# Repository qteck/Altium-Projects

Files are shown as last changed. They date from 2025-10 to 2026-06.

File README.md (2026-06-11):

# Optical Receiver Design 
The optical receiver is designed with two signal paths: one for oscilloscope monitoring and debugging, and one for audio output. The design balances bandwidth, gain, loading, noise filtering, DC offset removal, and testability. Gain is distributed across multiple stages to maintain bandwidth and reduce distortion while buffering and appropriate stage impedance ratios are used to minimize loading effects.

## Layout Characteristics
The receiver is divided into two signal paths:
- Path 1: Scope/debugging output
- Path 2: Audio output

## Design Variables Considered
The design takes into account the following trade-offs and constraints:
- Bandwidth versus signal magnitude
- Loading effect versus signal magnitude
- Signal damping versus gain
- Filtering of coupled noise using passive filters and the properties of IC packages
- Bidirectional power supply requirements
- Signal level shifting
- DfX considerations, especially design for testing

## Mitigation Techniques
The following techniques are used to improve signal quality, stability, and testability:
- Buffering to reduce loading effects 
- Consecutive stage loading with an approximate factor of 10 between stages 
- Minimising gain per stage to maximise bandwidth 
- Splitting gain across multiple stages to retain bandwidth while increasing total gain 
- Selecting appropriate gain values to minimise signal distortion 
- Using passive filters to reduce coupled noise at reasonable cost 
- Removing DC offset by introducing a high-pass filter 
- Adding test pins and debugging connections with reasonably sized components for easier testing and troubleshooting
  
## Signal Paths 
Path 1: 
Purpose: Receive optical signal and amplify the current from the detector into processable voltage levels using the sullen keys with a scope connection for debugging.

Stages: TIA → DC blocker / HPF → Sallen-Key Filter 1 → Sallen-Key Filter 2 → Scope Output

Path 2: 
Purpose: Provide audible output with industry grade audio op amp and passive low pass filter in the path.

Stages: TIA → DC blocker / HPF → Sallen-Key Filter 1 → Sallen-Key Filter 2 → LPF2 → LPF3 → Pre-Amplifier → Audio Amplifier

## PCB Front Side
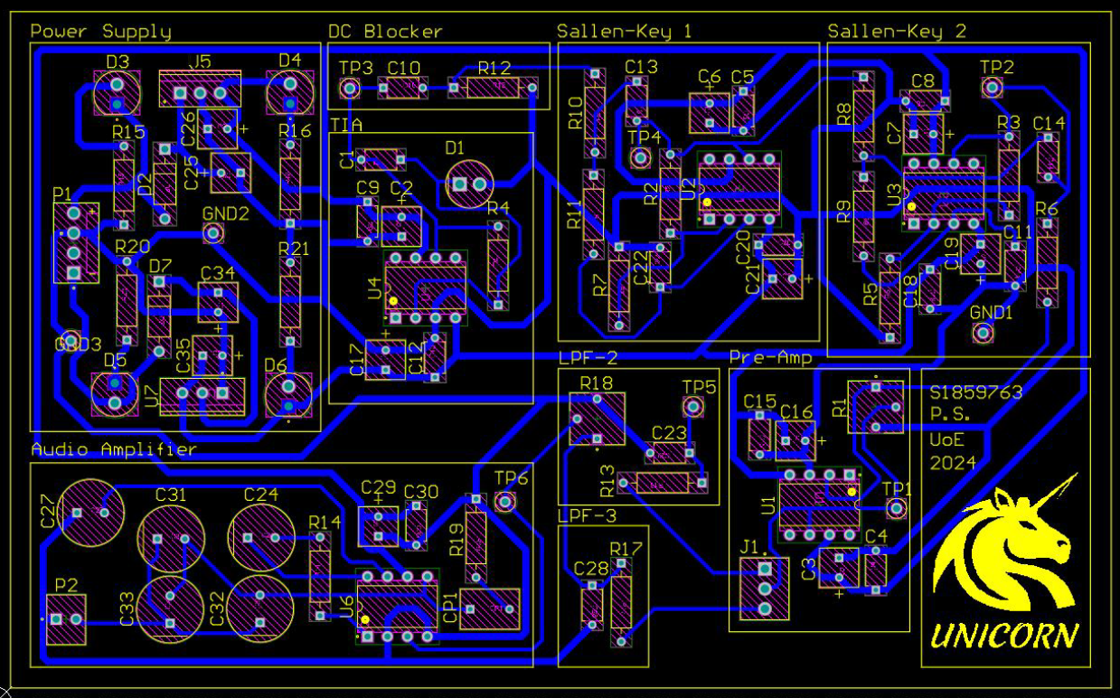
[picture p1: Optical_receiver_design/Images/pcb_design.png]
Whole System


## System Capture
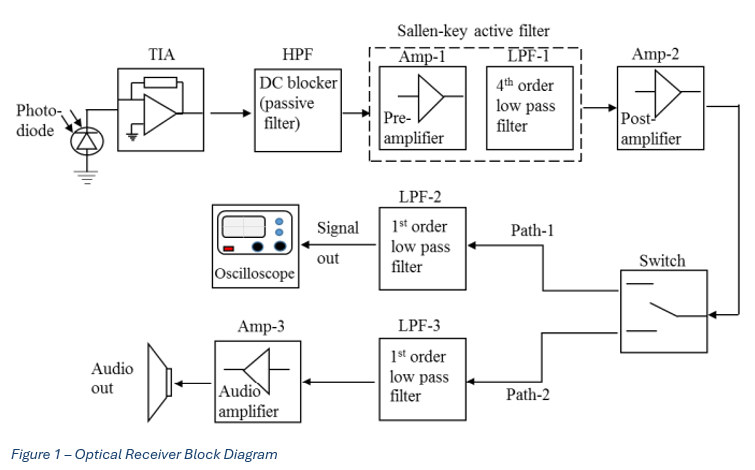
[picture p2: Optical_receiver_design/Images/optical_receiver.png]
System Capture


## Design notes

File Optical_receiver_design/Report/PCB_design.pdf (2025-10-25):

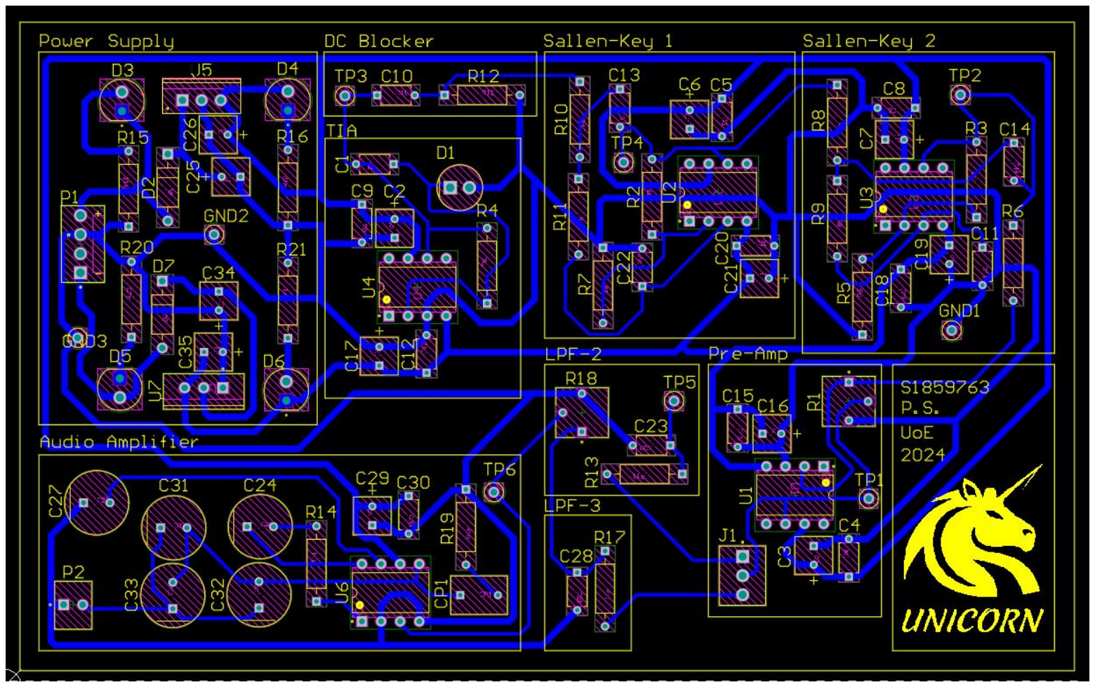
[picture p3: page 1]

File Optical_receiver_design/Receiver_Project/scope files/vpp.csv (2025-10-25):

x-axis | 1
second | Volt
-1.900000E-06 | -42.592964601E-03
-1.895000E-06 | -40.180904325E-03
-1.890000E-06 | -39.778894279E-03
-1.885000E-06 | -40.180904325E-03
-1.880000E-06 | -42.994974647E-03
-1.875000E-06 | -39.778894279E-03
-1.870000E-06 | -44.201004785E-03
-1.865000E-06 | -40.984924417E-03
-1.860000E-06 | -41.386934463E-03
-1.855000E-06 | -40.984924417E-03
-1.850000E-06 | -42.592964601E-03
-1.845000E-06 | -40.180904325E-03
-1.840000E-06 | -38.974874187E-03
-1.835000E-06 | -41.386934463E-03
-1.830000E-06 | -43.798994739E-03
-1.825000E-06 | -40.582914371E-03
-1.820000E-06 | -41.788944509E-03
-1.815000E-06 | -36.160803866E-03
-1.810000E-06 | -40.582914371E-03
-1.805000E-06 | -38.572864141E-03
-1.800000E-06 | -40.582914371E-03
-1.795000E-06 | -38.974874187E-03
-1.790000E-06 | -37.768844049E-03
-1.785000E-06 | -38.170854095E-03
-1.780000E-06 | -38.170854095E-03
-1.775000E-06 | -39.376884233E-03
-1.770000E-06 | -40.984924417E-03
-1.765000E-06 | -39.778894279E-03
-1.760000E-06 | -40.582914371E-03
-1.755000E-06 | -35.356783774E-03
-1.750000E-06 | -42.190954555E-03
-1.745000E-06 | -36.964823958E-03
-1.740000E-06 | -40.180904325E-03
-1.735000E-06 | -36.562813912E-03
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

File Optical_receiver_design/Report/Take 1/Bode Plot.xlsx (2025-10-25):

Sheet: List1
FrA1:E16eq, f(Khz) | Vin(mV) | Vout (V) | Vout/Vin | G=20log(Vout/Vin) (Db) | Vout (V) | Vout/Vin |  | G=20log(Vout/Vin) (Db) |  | Freq, f(khz) | Vin(mV) | Vout (V) | Vout/Vin | G=20log(Vout/Vin) (Db)
200 | 0.125 | 0.092 | 0.736 | -2.662 | 0.80 | #REF! |  | #REF! |  | 10 | 0.12 | 1.65 | 13.20 | 22.41
600 | 0.125 | 0.086 | 0.688 | -3.248 | 1.00 | #REF! |  | #REF! |  | 20 | 0.12 | 1.44 | 11.52 | 21.23
1000 | 0.125 | 0.074 | 0.592 | -4.554 | 1.30 | #REF! |  | #REF! |  | 30 | 0.12 | 1.22 | 9.76 | 19.79
1400 | 0.125 | 0.073 | 0.584 | -4.672 | 1.40 | #REF! |  | #REF! |  | 40 | 0.12 | 1.00 | 8.00 | 18.06
1800 | 0.125 | 0.070 | 0.560 | -5.036 | 1.50 | #REF! |  | #REF! |  | 50 | 0.12 | 0.86 | 6.88 | 16.75
2200 | 0.125 | 0.068 | 0.544 | -5.288 | 1.50 | #REF! |  | #REF! |  | 60 | 0.12 | 0.75 | 6.00 | 15.56
2600 | 0.125 | 0.066 | 0.528 | -5.547 | 1.50 | #REF! |  | #REF! |  | 70 | 0.12 | 0.68 | 5.44 | 14.71
3000 | 0.125 | 0.060 | 0.480 | -6.375 | 1.50 | #REF! |  | #REF! |  | 80 | 0.12 | 0.61 | 4.88 | 13.77
3400 | 0.125 | 0.055 | 0.440 | -7.131 | 1.60 | #REF! |  | #REF! |  | 90 | 0.12 | 0.52 | 4.16 | 12.38
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

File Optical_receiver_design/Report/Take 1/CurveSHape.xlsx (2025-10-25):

x-axis | 1
second | Volt
-2.94e-06
-2.935e-06 | -0.001459798776
-2.93e-06 | -0.001459798776
-2.925e-06 | -0.002263818868
-2.92e-06 | -0.003067838959
-2.915e-06 | -0.001459798776
-2.91e-06 | -0.005479899235
-2.905e-06 | -0.005479899235
-2.9e-06 | -0.004675879143
-2.895e-06 | -0.005479899235
-2.89e-06 | -0.002263818868
-2.885e-06 | -0.006283919327
-2.88e-06 | -0.007891959511
-2.875e-06 | -0.01110803988
-2.87e-06 | -0.004675879143
-2.865e-06 | -0.008695979603
-2.86e-06 | -0.006283919327
-2.855e-06 | -0.006283919327
-2.85e-06 | -0.007087939419
-2.845e-06 | -0.007891959511
-2.84e-06 | -0.006283919327
-2.835e-06 | -0.006283919327
-2.83e-06 | -0.007087939419
-2.825e-06 | -0.009499999695
-2.82e-06 | -0.009499999695
-2.815e-06 | -0.01191205997
-2.81e-06 | -0.007087939419
-2.805e-06 | -0.01271608006
-2.8e-06 | -0.01271608006
-2.795e-06 | -0.01271608006
-2.79e-06 | -0.01271608006
-2.785e-06 | -0.01754020061
-2.78e-06 | -0.007891959511
-2.775e-06 | -0.01754020061
-2.77e-06 | -0.01754020061
-2.765e-06 | -0.01512814034
-2.76e-06 | -0.01432412025
-2.755e-06 | -0.01754020061
-2.75e-06 | -0.01593216043
-2.745e-06 | -0.01432412025
-2.74e-06 | -0.01432412025
-2.735e-06 | -0.01834422071
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

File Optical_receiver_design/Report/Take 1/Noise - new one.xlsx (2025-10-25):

x-axis
second | Volt | Noise recorderd when V = 0.086
-2.94e-06
-2.94e-06 | 4.17E-03
-2.93e-06 | 4.97E-03
-2.93e-06 | 6.58E-03
-2.92e-06 | 2.56E-03
-2.92e-06 | 6.58E-03
-2.91e-06 | 7.38E-03
-2.91e-06 | 6.58E-03
-2.9e-06 | 3.36E-03
-2.9e-06 | 7.38E-03
-2.89e-06 | 7.38E-03
-2.89e-06 | 7.38E-03
-2.88e-06 | 5.78E-03
-2.88e-06 | 6.58E-03
-2.87e-06 | 6.58E-03
-2.87e-06 | 4.97E-03
-2.86e-06 | 3.36E-03
-2.86e-06 | 4.97E-03
-2.85e-06 | 4.17E-03
-2.85e-06 | 3.36E-03
-2.84e-06 | 4.97E-03
-2.84e-06 | 5.78E-03
-2.83e-06 | 7.38E-03
-2.83e-06 | 3.36E-03
-2.82e-06 | 4.97E-03
-2.82e-06 | 4.97E-03
-2.81e-06 | 7.38E-03
-2.81e-06 | 5.78E-03
-2.8e-06 | 4.17E-03
-2.8e-06 | 6.58E-03
-2.79e-06 | 7.38E-03
-2.79e-06 | 4.97E-03
-2.78e-06 | 1.48E-04
-2.78e-06 | 9.52E-04
-2.77e-06 | 3.36E-03
-2.77e-06 | 1.76E-03
-2.76e-06 | 4.17E-03
-2.76e-06 | 5.78E-03
-2.75e-06 | 4.97E-03
-2.75e-06 | 8.19E-03
-2.74e-06 | 6.58E-03
-2.74e-06 | 8.99E-03
-2.73e-06 | 3.36E-03
-2.73e-06 | 5.78E-03
-2.72e-06 | 4.97E-03
-2.72e-06 | 6.58E-03
-2.71e-06 | 3.36E-03
-2.71e-06 | 4.97E-03
-2.7e-06 | 4.97E-03
-2.7e-06 | 7.38E-03
-2.69e-06 | 4.97E-03
-2.69e-06 | 3.36E-03
-2.68e-06 | 5.78E-03
-2.68e-06 | 4.17E-03
-2.67e-06 | 3.36E-03
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

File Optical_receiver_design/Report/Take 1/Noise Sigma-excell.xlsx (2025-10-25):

x-axis |  | trasmitter off - noise signal
second | Volt
-2.93e-06
-2.92e-06
-2.92e-06 | -0.0568
-2.91e-06 | -0.0468
-2.91e-06 | -0.0367 |  |  |  | noise floor image
-2.9e-06 | -0.0447
-2.9e-06 | -0.0407
-2.89e-06 | -0.0528
-2.89e-06 | -0.0407
-2.88e-06 | -0.0387
-2.88e-06 | -0.0447
-2.87e-06 | -0.0387
-2.87e-06 | -0.0367
-2.86e-06 | -0.0488
-2.86e-06 | -0.0367
-2.85e-06 | -0.0367
-2.85e-06 | -0.0387
-2.84e-06 | -0.0387
-2.84e-06 | -0.0387
-2.83e-06 | -0.0387
-2.83e-06 | -0.0307
-2.82e-06 | -0.0468
-2.82e-06 | -0.0468 |  | -0.05069555208 | -0.0507
-2.81e-06 | -0.0468
-2.81e-06 | -0.0548
-2.8e-06 | -0.0407
-2.8e-06 | -0.0528
-2.79e-06 | -0.0528
-2.79e-06 | -0.0447
-2.78e-06 | -0.0548
-2.78e-06 | -0.0528
-2.77e-06 | -0.0528
-2.77e-06 | -0.0628
-2.76e-06 | -0.0468
-2.76e-06 | -0.0568
-2.75e-06 | -0.0468
-2.75e-06 | -0.0689
-2.74e-06 | -0.0628
-2.74e-06 | -0.0488
-2.73e-06 | -0.0528
-2.73e-06 | -0.0628
-2.72e-06 | -0.0628
-2.72e-06 | -0.0468
-2.71e-06 | -0.0548
-2.71e-06 | -0.0548
-2.7e-06 | -0.0548
-2.7e-06 | -0.0548
-2.69e-06 | -0.0689
-2.69e-06 | -0.0548
-2.68e-06 | -0.0468
-2.68e-06 | -0.0648
-2.67e-06 | -0.0508
-2.67e-06 | -0.0488
-2.66e-06 | -0.0608
-2.66e-06 | -0.0468
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

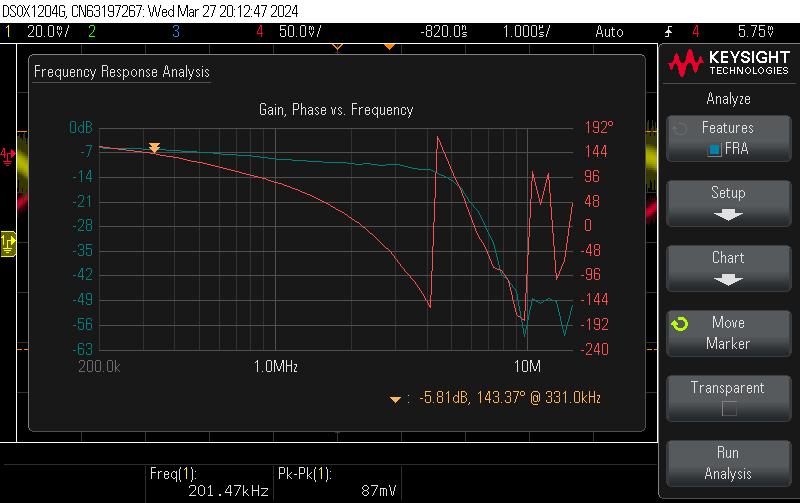
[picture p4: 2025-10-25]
Optical_receiver_design/Report/Take 3/scope_26.png

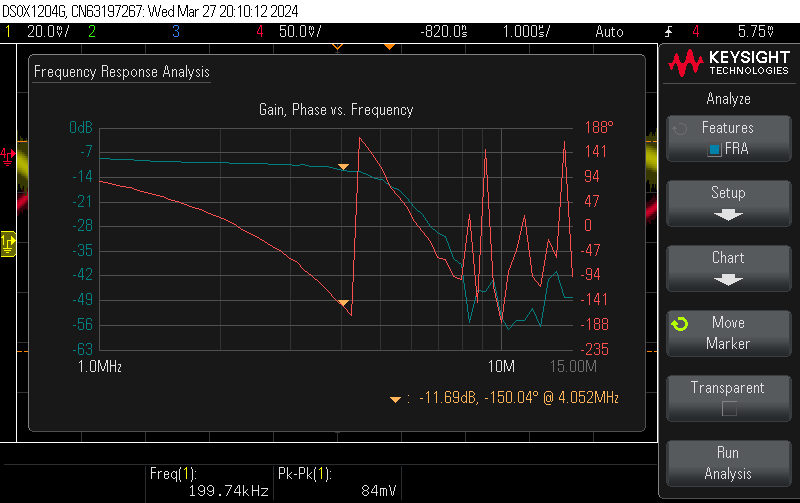
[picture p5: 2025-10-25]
Optical_receiver_design/Report/Take 3/scope_25.png

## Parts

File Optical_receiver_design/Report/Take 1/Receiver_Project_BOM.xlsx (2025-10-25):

Comment | Description | Designator | Supplier | Note | Mouser No. | Quantity | Price per 10 units | Final price
8p | Ceramic Disc Capacitors 8pF 5% | C1 | mouser.co.uk |  | 75-561R10TCCV80BA | 1 | £6.39 | £6.39
2.2u | CAP TANT 10UF 10% 16V RADIAL | C2, C3, C6, C7, C16, C17, C19, C21, C29 | 'mouser.co.uk |  | T350C225K035AT7301 | 9 | £22.50 | £202.50
0.1n | Capacitors MLCC - Leaded 100pF 50volts 5% | C4, C5, C8, C9, C12, C15, C18, C20, C30 | mouser.co.uk |  | 594-K101J15C0GF5TL2 | 9 | £0.89 | £8.01
22n | Ceramic Disc Capacitors 100V 22nF -20% | C10 | mouser.co.uk |  | 594-D223Z39Y5VH63L2R | 1 | £1.92 | £1.92
100p | Capacitors MLCC - Leaded 100pF 50V 5% | C11, C14 | mouser.co.uk |  | 594-K101J15C0GF5TH5 | 2 | £0.89 | £1.78
56p | Capacitors MLCC - Leaded 56pF 50V 5% | C13, C22 | mouser.co.uk |  | 594-K560J15C0GF5TL2 | 2 | £0.87 | £1.74
68p | Ceramic Disc Capacitors 68pF 5% 3Kvolts | C23 | mouser.co.uk |  | 75-564R3DF0Q68 | 1 | £0.82 | £0.82
10u | Electrolytic Capacitors - Radial Leaded 16VDC 10uF | C24, C27 | mouser.co.uk | for 50G | 667-ECE-A1CKS100B | 0 | £0.09 | £0.00
0.33u | Tantalum Capacitors - Solid Leaded 35volt 0.33uF 10% | C25, C34 | mouser.co.uk |  | 80-T355A334K035AT | 2 | £2.29 | £4.58
0.1u | Tantalum Capacitors- 50V 0.1uF 20% ESR = 26 Ohm | C26, C35 | mouser.co.uk |  | 581-TAP104M050CCS | 2 | £0.32 | £0.64
1n | Capacitors MLCC - Leaded 1000pF 50volts 5% | C28 | mouser.co.uk |  | 594-K102J15C0GF5TH5 | 1 | £0.18 | £0.18
47uF | Electrolytic Capacitor - Radial Leaded 100VDC 47uF 590mA | C31 | mouser.co.uk |  | 667-EEU-FS2A470LB | 1 | £0.31 | £0.31
100uF | Electrolytic Capacitors - Radial Leaded 25VDC 100uF | C32, C33 | mouser.co.uk |  | 667-ECE-A1EKS101I | 2 | £0.22 | £0.44
47n | Film Capacitors 0.047uF 100V 5% | CP1 | mouser.co.uk |  | 75-MKT1817347014 | 1 | £0.43 | £0.43
78-TEFD4300F | Photodiodes T-1 770 to 1070nm +/-20 deg | D1 | mouser.co.uk |  | 78-TEFD4300F | 1 | £3.33 | £3.33
1N4007 | Rectifiers Diode, DO-41, 1000V, 1A | D2, D2 | mouser.co.uk |  | 637-1N4007 | 2 | £0.05 | £0.11
RED | Standard LEDs - Through Hole, T-1 3/4 (5 mm) | D3, D5 | mouser.co.uk |  | 645-521-9651F | 2 | £8.86 | £17.72
GREEN | Standard LEDs - Through Hole, T-1 3/4 (5 mm) | D4, D6 | mouser.co.uk |  | 645-521-9651F | 2 | £8.86 | £17.72
Test pins | Test Plugs & Test Jacks BLACK TEST POINT | GND1, GND2, GND3 | mouser.co.uk |  | 534-5011 | 3 | £1.76 | £5.28
Slide Switch | Slide Switches 8.8 x 3.9 x 3.5 mm, 2 mm | J1 | mouser.co.uk |  | 179-SLW-883935-2A-D | 1 | £3.50 | £3.50
Power connection | Male Header, Pitch 2.54 mm, 1 x 4 Pos, Height 10.03 mm, Tail Length 3.56 mm | P1 | mouser.co.uk |  | 571-2369991-4 | 1 | £18.70 | £18.70
Board output | Female Header, Pitch 2.54 mm, 1 x 2 Pos, Height 10.67 mm, Tail Length 3.56 mm | P2 | mouser.co.uk |  | 649-71363-302LF | 1 | £2.30 | £2.30
Trimmer pot 100k | Trimmer 104 - 'Through Hole 1/4"SQ 100KOHMS 10% | R1 | mouser.co.uk |  | 652-3362U-1-104ALF | 1 | £11.60 | £11.60
1.8k | Resistor 2W, 500V, 5% | R2, R3 | uk.farnell.com |  | 3229913 | 2 | £2.90 | £5.80
3k3 | 5W, 500V, 5% | R4 | uk.farnell.com |  | 2324626 | 1 | £3.80 | £3.80
2.2k | 5W, 500V, 5% | R5, R7 | uk.farnell.com |  | 1306252 | 2 | £4.70 | £9.40
10k | 5W, 500V, 5% | R6 | uk.farnell.com |  | 3229934 | 1 | £3.90 | £3.90
270 | '5W, 500V, 5% | R8, R9 | uk.farnell.com |  | 3229892 | 2 | £3.90 | £7.80
470 | '5W, 150V, 5% | R10, R11 | uk.farnell.com |  | 2340995 | 2 | £4.70 | £9.40
4k7 | '5W, 500V, 5% | R12 | uk.farnell.com |  | 3229925 | 1 | £3.90 | £3.90
330 | '5W, 500V, 5% | R13 | uk.farnell.com |  | 3229894 | 1 | £3.90 | £3.90
1k2 | '5W, 500V, 5% | R14 | uk.farnell.com | for 50G | 3605426 | 0 | £4.90 | £0.00
2k2 | '5W, 500V, 5% | R15, R20 | uk.farnell.com |  | 3229915 | 2 | £3.80 | £7.60
33K | '5W, 500V, 5% | R16, R21 | uk.farnell.com |  | 3229947 | 2 | £4.00 | £8.00
1k5 | '5W, 500V, 5% | R17 | uk.farnell.com |  | 3229911 | 1 | £3.10 | £3.10
Trimmer pot 10k | Trimmer Resistors - Through Hole 1/4"SQ 10KOHMS 10% | R18 | uk.farnell.com |  | 652-3362H-1-103LF | 1 | £10.30 | £10.30
10 | RES 1K OHM 0.6W 1% AXIAL | R19 | uk.farnell.com |  | 3229854 | 1 | £4.00 | £4.00
Test pins | Test Plugs & Test Jacks BLACK TEST POINT | TP1, TP2, TP3, TP4, TP5, TP6 | mouser.co.uk |  | 534-5011 | 6 | £1.76 | £10.56
LM6171 | High Speed Low Power Low Distortion Voltage Feedback Amplifier, 8-pin MDIP | U1, U2, U3 | mouser.co.uk |  | 926-LM6171BIN/NOPB | 3 | £38.60 | £115.80
LM318N | Operational Amplifier, 8-pin MDIP | U4 | mouser.co.uk |  | 595-LM318P | 1 | £11.50 | £11.50
LM78L12ACZ | Positive Voltage Regulator, 5V, 3-Pin TO-220 | U5 | mouser.co.uk |  | 926-LM78L12ACZ/NOPB | 1 | £4.88 | £4.88
LM386N-1 | Low Voltage Audio Power Amplifier, 0 to 70 degC, 8-pin DIP (P8) | U6 | mouser.co.uk |  | 926-LM386N-1/NOPB | 1 | £7.59 | £7.59
LM79L12 | 3-Terminal Negative Regulator, 3-pin TO-220, Pb-Free | U7 | mouser.co.uk |  | 863-MC79L12ACPRPG | 1 | £2.70 | £2.70
 | PCB | PCB | jlcpcb.com |  |  | 1 | £2.00 | £2.00
 | 8 DIP amplifier sockets, 2.54 mm, 7.62 mm | Socket U1, U2, U3, U4 | uk.farnell.com |  | 2445620 | 0 | £1.69 | £0.00
 | Shipment | Transport | FedEX |  |  | 1 | £20.00 | £20.00
 |  |  |  |  |  |  | Total per 10 units | £543.93
 |  |  |  |  |  |  | Total per 1 unit | £54.39

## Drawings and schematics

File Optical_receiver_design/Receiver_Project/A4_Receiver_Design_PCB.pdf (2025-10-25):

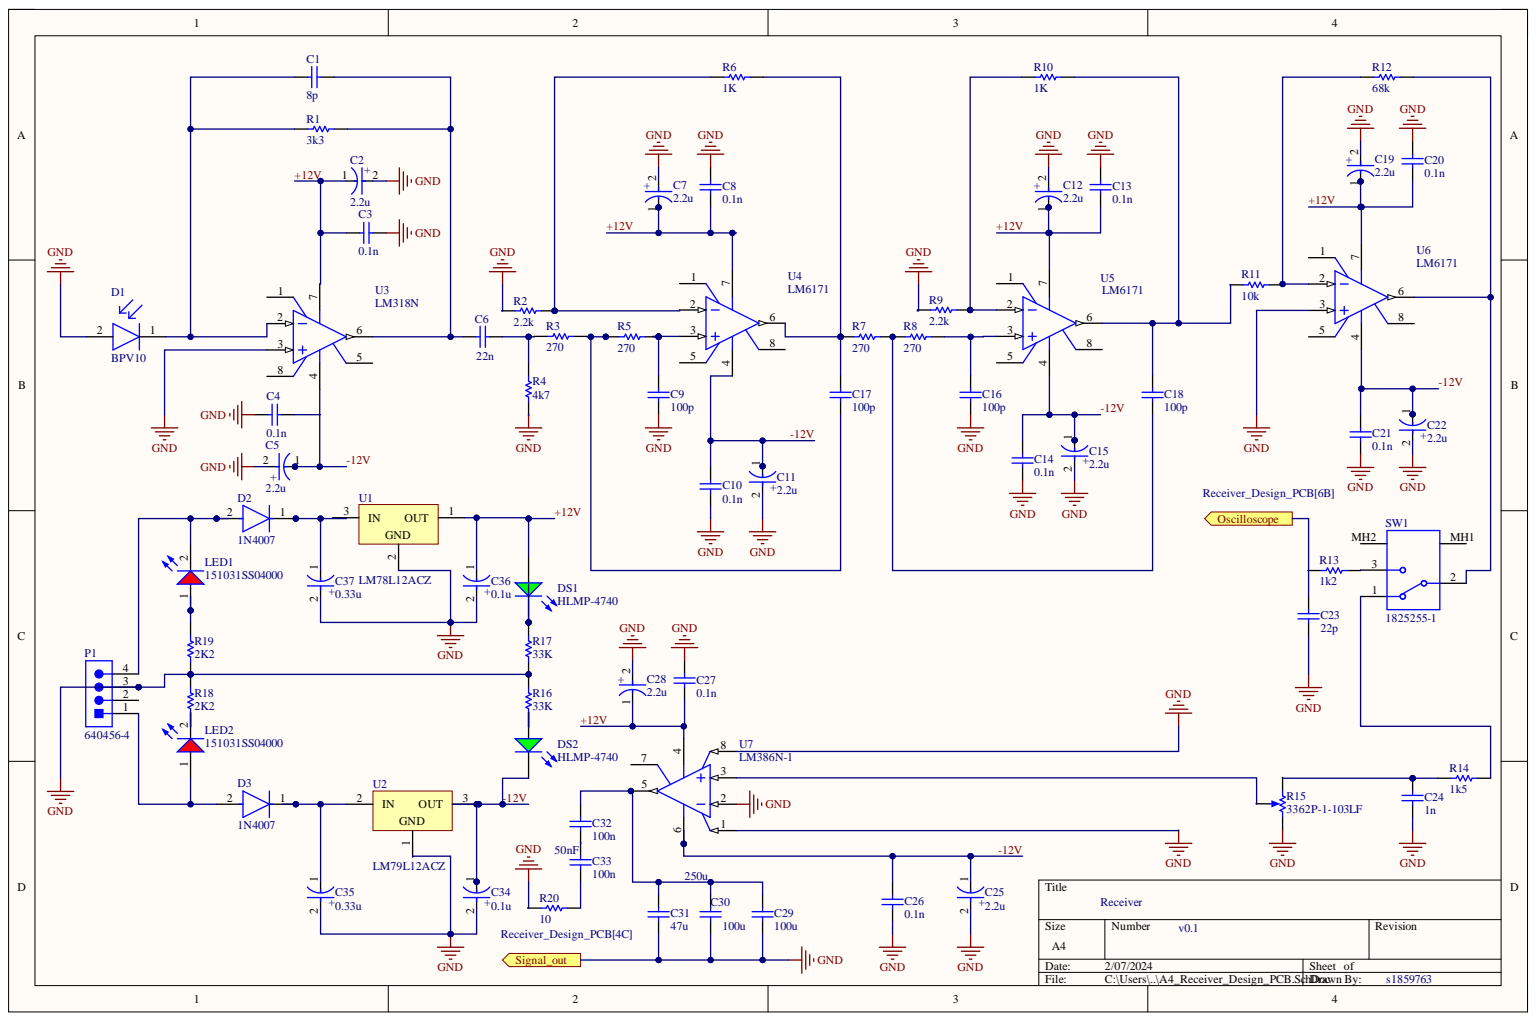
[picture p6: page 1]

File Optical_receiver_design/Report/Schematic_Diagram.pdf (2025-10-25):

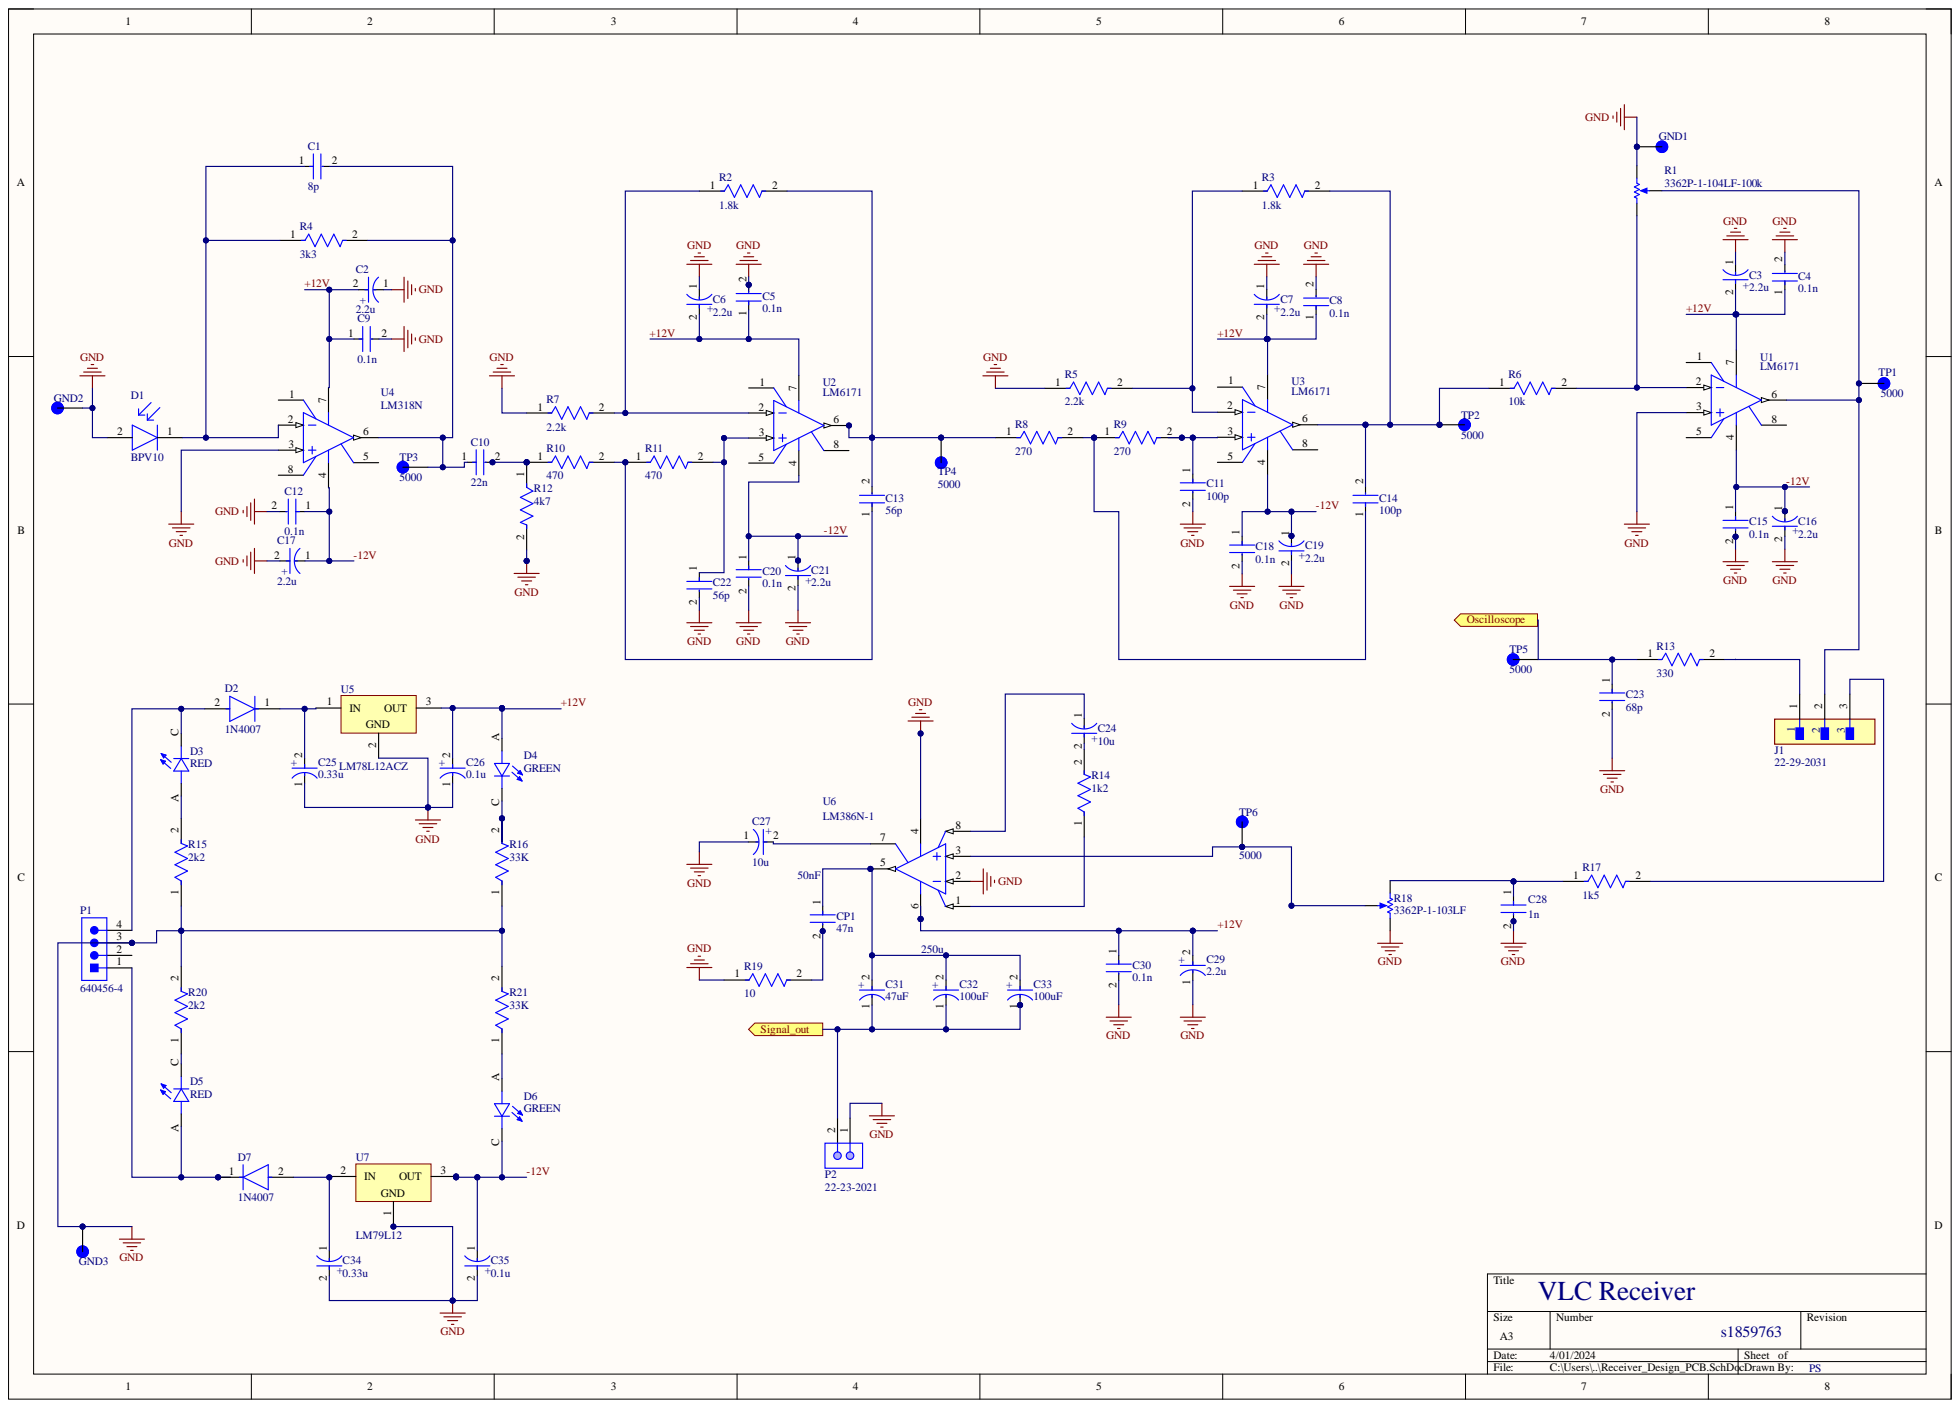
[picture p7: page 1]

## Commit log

2025-10-25 Analogue Laboratory 3 - Receiver Design
    [A4_Receiver_Design_PCB.SchDoc, Bode Plot.xlsx, CurveSHape.xlsx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]
2026-06-11 root path correction
    [A4_Receiver_Design_PCB.SchDoc, Bode Plot.xlsx, CurveSHape.xlsx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]
